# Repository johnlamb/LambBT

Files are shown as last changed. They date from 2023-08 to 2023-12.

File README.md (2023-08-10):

# LambBT
## Split wireless keyboard

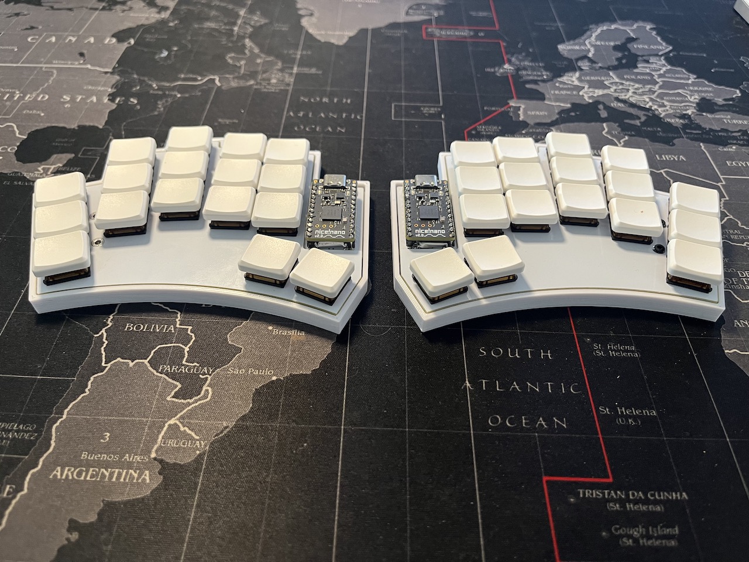
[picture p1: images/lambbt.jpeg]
LambBT


A small 34 key split wireless keyboard with Choc V1 switches heavily inspired by the Sweep family and Architeuthis Dux. The columns have the same splay as the AD and is great for starting to experiment with splays.

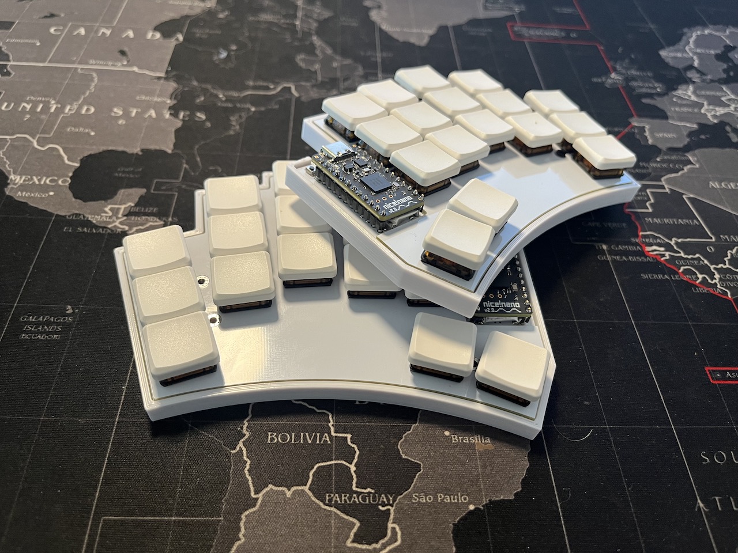
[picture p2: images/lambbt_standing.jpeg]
LambBT Side


The keyboard uses hotswap and a top plate together with a 3D printed case with M2 insets. 

Socketing the Nice!Nano v2 allows the battery to fit under the MCU. The MCU can face both up and down on either split. For a face up orientation, as in the pictures, solder the MCU bridges on the top. For a face down orientation, solder the MCU bridges on the bottom/back side.

I opted to skip an external battery JST connector and instead use two battery holes to solder the wires. Ensure right polarity, the positive end (usually red) goes in the left hole on the left split, and the right hole on the right split(towards the key switches) whereas the negative/ground (usually black) goes in the outer hole (right hole on the left split and left hole on the right split).

On/Off switch with a case cutout and a reset switch that wont be accidentally triggered.

## Design
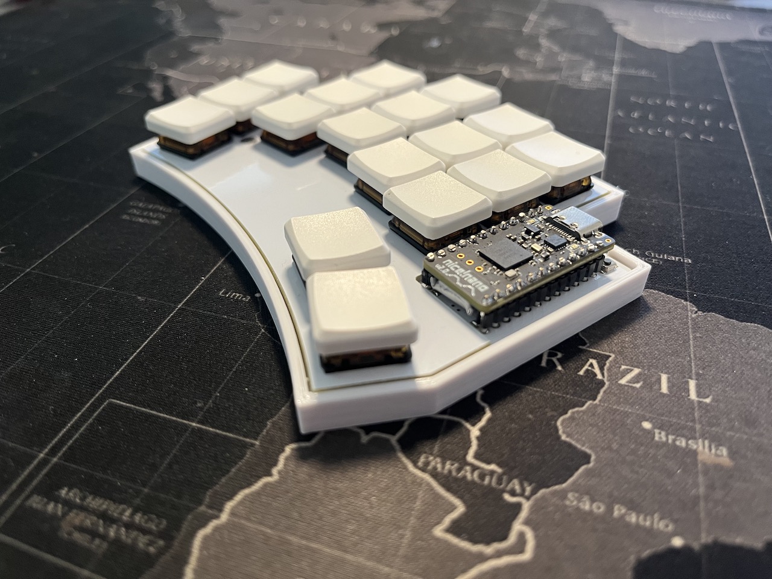
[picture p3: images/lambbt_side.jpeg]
LambBT Detail


Designed from the ground up using Ergogen and the routing in KiCad. Files for the pcb and case are in the [Ergogen](ergogen) folder together with ready made gerber files for both the pcb and plate.

Stl-files for the case are in the [output/case](ergogen/output/cases) folder.

## Build

To build for yourself, mae sure Ergogen CLI is installed. Then download/clone this repo, stand in the ergogen folder and issue the `ergogen .` command.

To also generate the case files, use the full:
`ergogen . && for i in output/cases/*.jscad; do npx @jscad/cli@1 "$i" -of stla ; done`

## Firmware
I use ZMK as firmware. You can find tested firmware and an initial keymap in the [lambbt_zmk repo](https://github.com/johnlamb/lambbt_zmk). Observer the standard keymap is Colemak-DH, if you want regular QWERTY, use the "default.keymap" file in the repo.

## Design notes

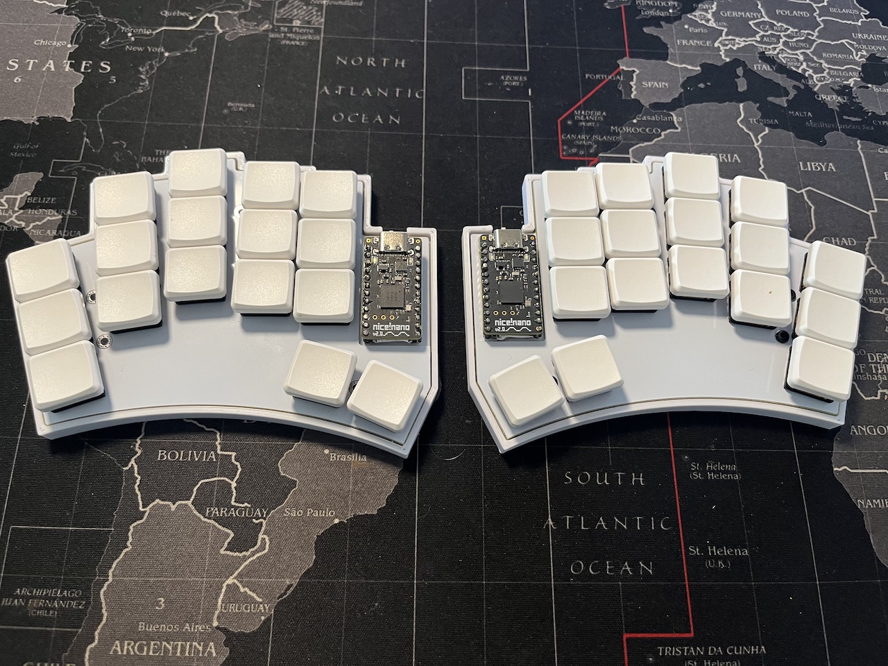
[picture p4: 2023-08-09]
images/lambbt2.jpeg

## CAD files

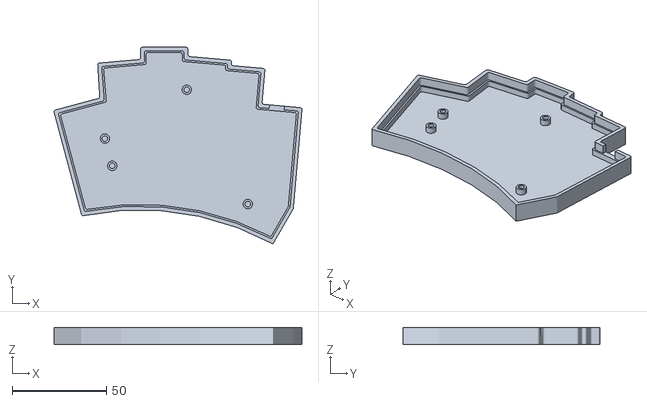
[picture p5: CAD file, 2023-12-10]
ergogen/output/cases/case_magnetic.stl
131.8 x 104.6 x 9.20

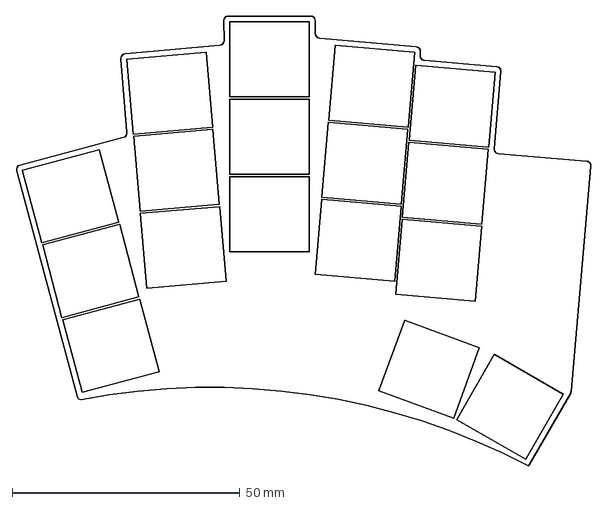
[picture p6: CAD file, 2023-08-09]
ergogen/output/outlines/combo.dxf
126.2 x 98.7 mm

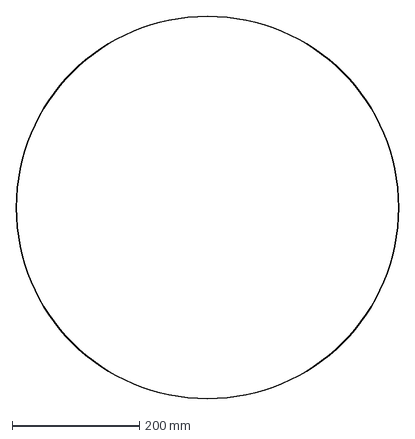
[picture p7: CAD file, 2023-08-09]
ergogen/output/outlines/cutout_circle_large.dxf
600.0 x 600.0 mm

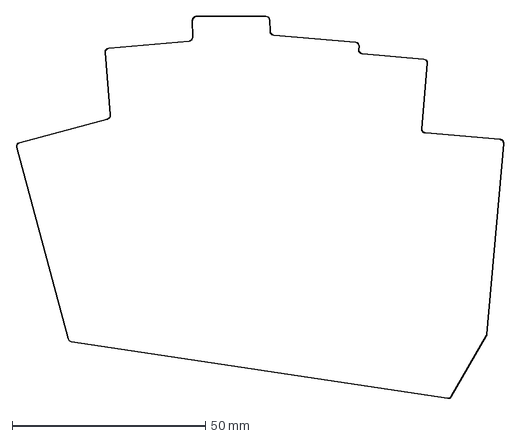
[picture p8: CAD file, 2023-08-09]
ergogen/output/outlines/board.dxf
126.2 x 99.0 mm

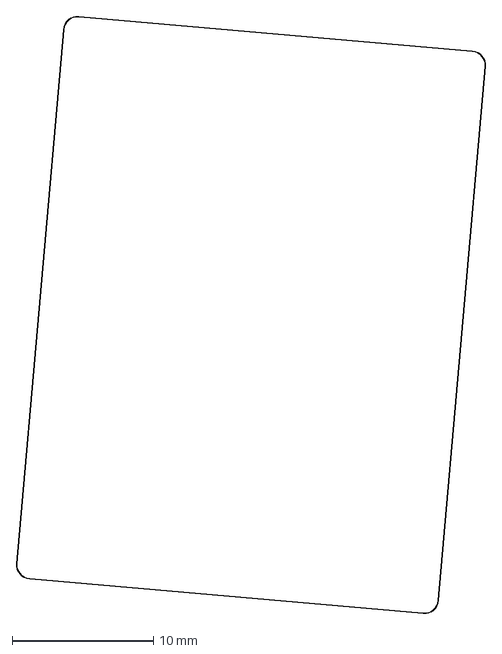
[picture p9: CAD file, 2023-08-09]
ergogen/output/outlines/mcucutout.dxf
33.3 x 42.4 mm

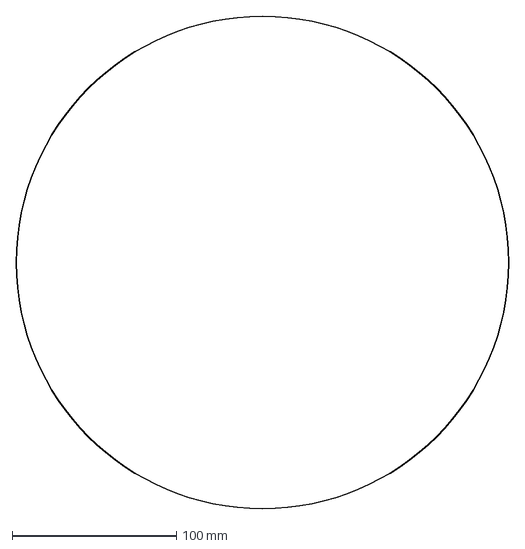
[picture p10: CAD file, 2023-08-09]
ergogen/output/outlines/cutout_circle_small.dxf
300.0 x 300.0 mm

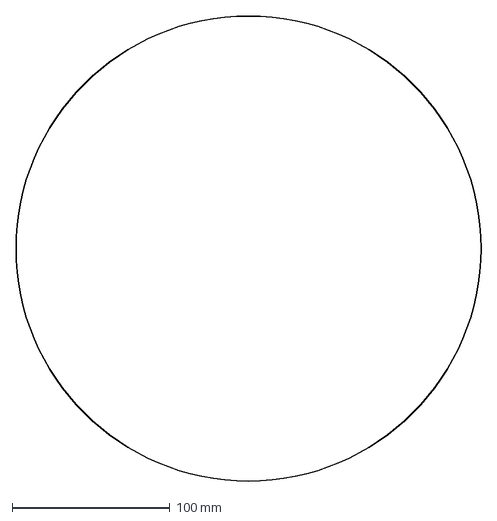
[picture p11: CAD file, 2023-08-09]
ergogen/output/outlines/cutout_circle_small_wall.dxf
295.0 x 295.0 mm

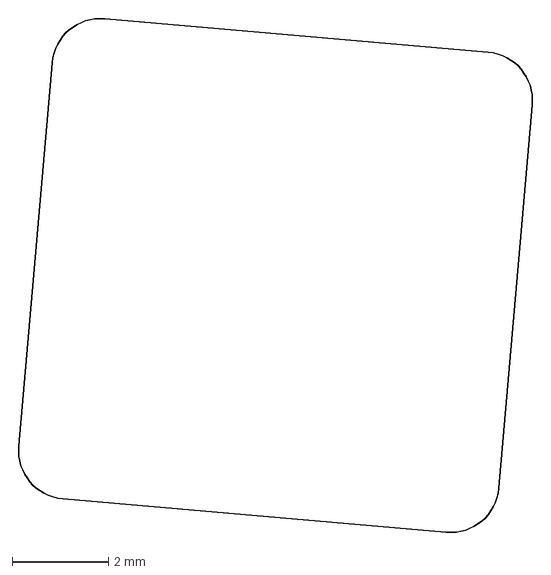
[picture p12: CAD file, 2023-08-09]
ergogen/output/outlines/usbcutout.dxf
10.8 x 10.8 mm

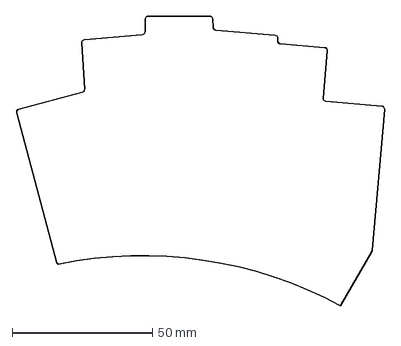
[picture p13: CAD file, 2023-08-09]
ergogen/output/outlines/xlplate.dxf
131.5 x 103.4 mm

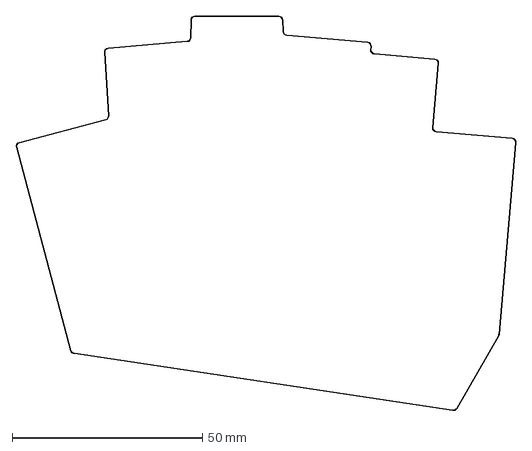
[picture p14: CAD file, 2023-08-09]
ergogen/output/outlines/xlboard.dxf
131.5 x 103.7 mm

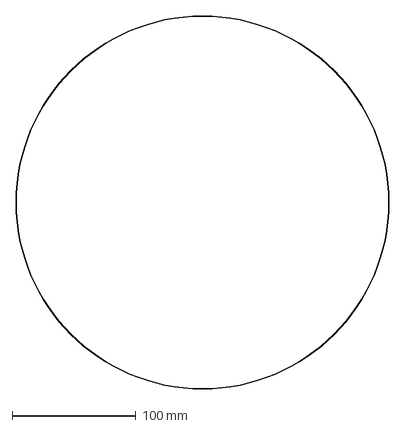
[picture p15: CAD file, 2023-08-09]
ergogen/output/outlines/cutout_circle_small_inner_inner_wall.dxf
300.8 x 300.8 mm

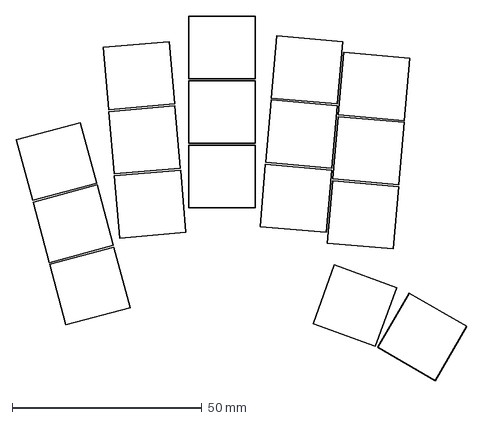
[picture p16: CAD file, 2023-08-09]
ergogen/output/outlines/keys.dxf
118.7 x 96.1 mm

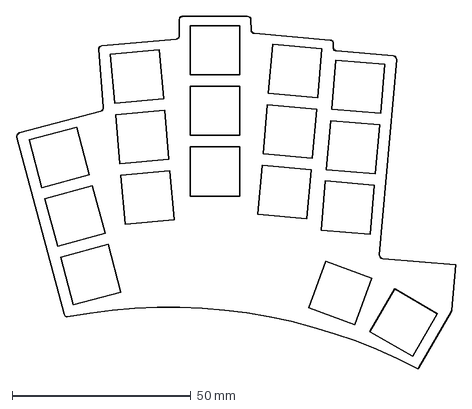
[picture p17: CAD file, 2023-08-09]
ergogen/output/outlines/plate.dxf
123.0 x 98.7 mm

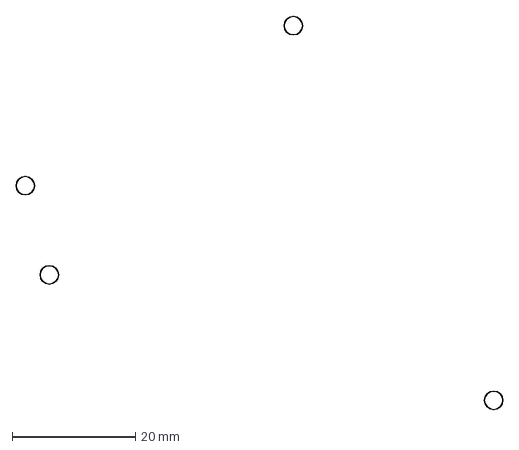
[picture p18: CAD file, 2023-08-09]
ergogen/output/outlines/mounting.dxf
79.0 x 63.8 mm

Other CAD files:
ergogen/output/outlines/cutout_circle_small_inner_wall.dxf
ergogen/output/outlines/standoff.dxf
ergogen/output/outlines/pcb.dxf
ergogen/output/outlines/switches.dxf

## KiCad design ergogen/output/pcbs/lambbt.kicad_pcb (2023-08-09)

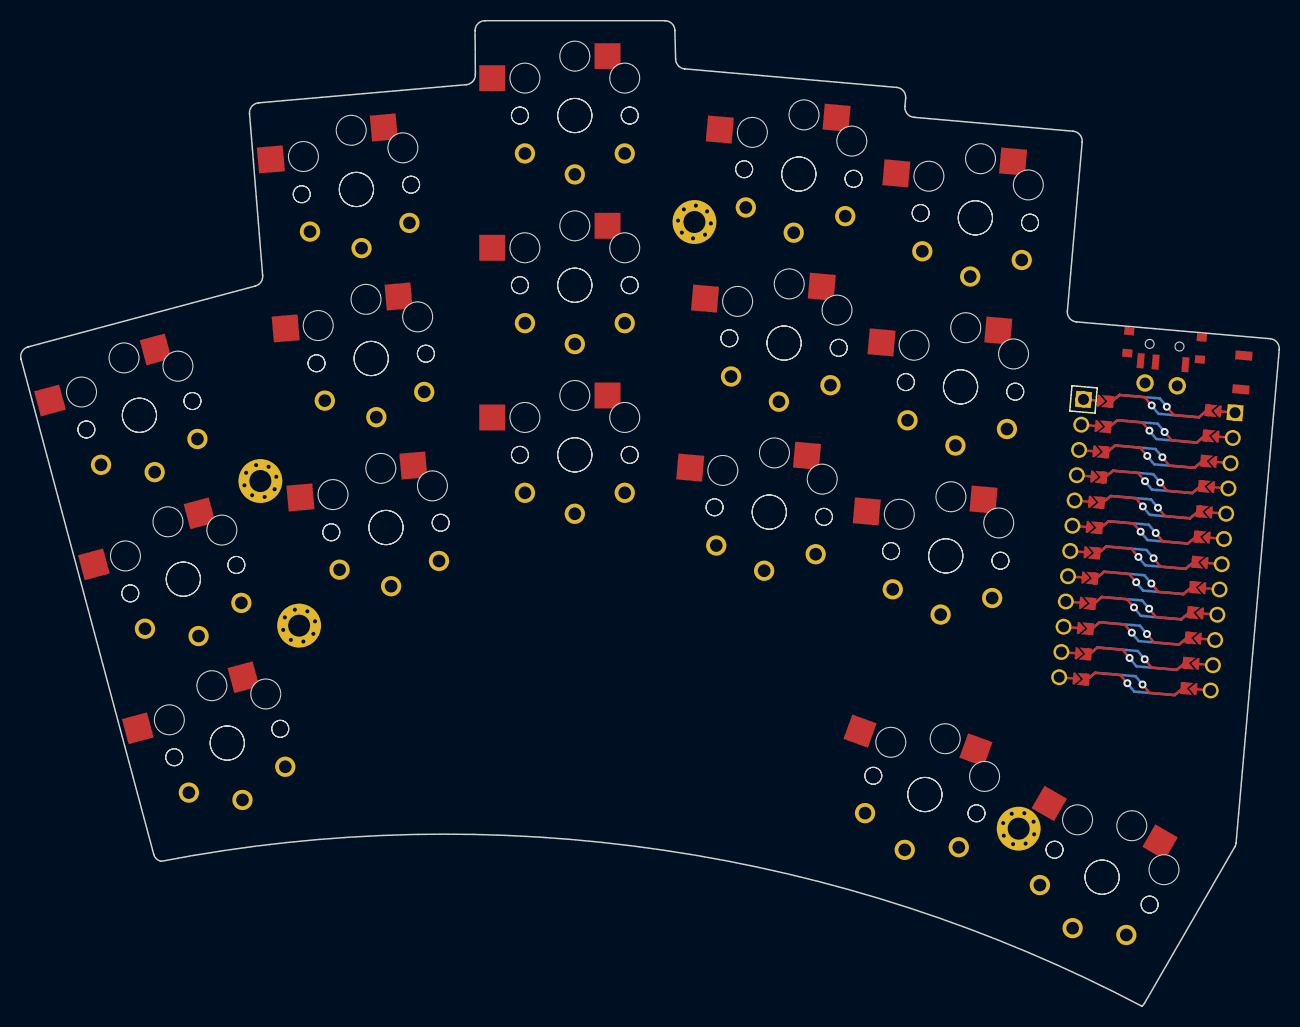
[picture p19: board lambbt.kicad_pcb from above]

Board: 2 copper layers, 126.1 x 98.7 mm, 39 parts (0 on the bottom side), 18 nets.

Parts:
MCU1: ProMicro
S1, S2, S3, S4, S5, S6, S7, S8, S9, S10, S11, S12, S13, S14, S15, S16, S17, S18, S19, S20, S21, S22, S23, S24, S25, S26, S27, S28, S29, S30, S31, S32, S33, S34: PG1350
_4, _5, _6, _7: MountingHole_2.2mm_M2_Pad_Via

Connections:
GND: MCU1.2, MCU1.21, MCU1.22, S1.2, S2.2, S3.2, S4.2, S5.2, S6.2, S7.2, S8.2, S9.2, S10.2, S11.2, S12.2, S13.2, S14.2, S15.2, S16.2, S17.2, S18.2, S19.2, S20.2, S21.2, S22.2, S23.2, S24.2, S25.2, S26.2, S27.2, S28.2, S29.2, S30.2, S31.2, S32.2, S33.2, S34.2
P0: MCU1.23, S14.1, S31.1
P1: MCU1.24, S15.1, S32.1
P2: MCU1.20, S13.1, S30.1
P3: MCU1.19, S12.1, S29.1
P4: MCU1.18, S11.1, S28.1
P5: MCU1.17, S10.1, S27.1
P6: MCU1.16, S9.1, S26.1
P7: MCU1.15, S8.1, S25.1
P8: MCU1.14, S7.1, S24.1
P9: MCU1.13, S6.1, S23.1
P10: MCU1.12, S5.1, S22.1
P14: MCU1.10, S3.1, S20.1
P15: MCU1.9, S2.1, S19.1
P16: MCU1.11, S4.1, S21.1
P18: MCU1.8, S1.1, S18.1
P19: MCU1.7, S16.1, S33.1
P20: MCU1.6, S17.1, S34.1

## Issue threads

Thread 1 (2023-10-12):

Complete list of hardware to build?

Mathrocker666, 2023-10-12:
Hey,

This keeb looks fantastic and I'd like to build one but I have a question: what exactly is needed to build it? M2 standoffs etc?

Thanks

johnlamb, 2023-10-13:
Thanks!
BOM:
2 pcbs, one for each side
2 MCUs, I am running Nice Nano v2
Legs and sockets for MCU socketing (https://docs.splitkb.com/hc/en-us/articles/360011263059-How-do-I-socket-a-microcontroller-)
2 batteries, I use 301230 3.7V 110mAh batteries that fits under the MCU when socketed.
34 hot swap sockets for Choc v1 switches
34 Choc v1 switches
34 choc v1 key caps
1 PCM12 surface mounted on/off switch
1 B3u1000 button for reset

Case:
3D print on left and one from the stl-files in the repo.
4 M2 threaded inserts
4 M2 screws, 4-5 mm long.

Closed 2023-10-13.

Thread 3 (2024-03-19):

Is top plate required to be used with the case?

ascodeasice, 2024-03-19:
Do I need the top plate to ensure the keyboard can fit in the case?

johnlamb, 2024-03-19:
No not needed, the pcb sits on a shelf on the bottom plate. Might even be easier to screw pcb to bottom plate without it. Purely aesthetic.

Closed 2024-03-19.

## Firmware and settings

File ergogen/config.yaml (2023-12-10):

units:
  kx: cx
  ky: cy

  pd: 2
  px: kx + pd
  py: ky + pd

  wpd: 2.5
  short_wpd: 0.5
  inner_wpd: -0.4

  # M2 screws
  screwsize: 1.5
  standoffsize: 2.5

  choc: 13.8

points:
  zones:
    matrix:
      # Fix placement on KiCAD sheet.
      anchor:
        shift: [150, -150]
      key:
        padding: 1ky
        spread: 1kx
      columns:
        pinky:
          key:
            splay: 15
          rows:
            bottom:
                column_net: P18
            home:
                column_net: P15
            top:
                column_net: P14
        ring:
          key:
            stagger: 17
            splay: -10
            origin: [0, -ky]
          rows:
            bottom:
                column_net: P16
            home:
                column_net: P10
            top:
                column_net: P9
        middle:
          key:
            stagger: 17/3
            splay: -5
            origin: [0, -ky]
          rows:
            bottom:
                column_net: P8
            home:
                column_net: P7
            top:
                column_net: P6
        index:
          key:
            stagger: -17/3
            splay: -5
            origin: [0, -ky]
          rows:
            bottom:
                column_net: P5
            home:
                column_net: P4
            top:
                column_net: P3
        inner:
          key:
            stagger: -17/6
          rows:
            bottom:
                column_net: P2
            home:
                column_net: P0
            top:
                column_net: P1
      rows:
        bottom:
        home:
        top:
    thumbs:
      key: 
        padding: 1ky
        spread: 1kx
      anchor:
        ref: matrix_inner_bottom
        shift: [0,-24]
      columns:
        inner:
          key:
            splay: -15
            column_net: P19
        outer:
          key:
            splay: -10
            origin: [-9, -9.5]
            column_net: P20
      rows:
        cluster:
outlines:
  keys:
    - what: rectangle
      where: true
      bound: false
      size: [kx-0.5, ky-0.5]
  switches:
    - what: rectangle
      where: true
      bound: false
      size: [choc, choc]
  cutout_circle_small:
    - what: circle
      radius: 150
      where:
        ref: matrix_middle_bottom
        shift: [-13,-188]
  cutout_circle_small_wall:
    - what: circle
      radius: 150-wpd
      where:
        ref: matrix_middle_bottom
        shift: [-13,-188]
  cutout_circle_small_inner_wall:
    - what: circle
      radius: 150-short_wpd
      where:
        ref: matrix_middle_bottom
        shift: [-13,-188]
  cutout_circle_small_inner_inner_wall:
    - what: circle
      radius: 150-inner_wpd
      where:
        ref: matrix_middle_bottom
        shift: [-13,-188]
  cutout_circle_large:
    - what: circle
      radius: 300
      where:
        ref: matrix_middle_bottom
        shift: [-38,-340]
  board:
    - what: polygon
      operation: stack
      points:
        - ref: matrix_pinky_top
          shift: [-0.5px, 0.5py]
        - ref: matrix_pinky_bottom
          shift: [-0.5px, -0.5py]
        - ref: thumbs_outer_cluster
          shift: [0.5px, -0.5py]
        - ref: thumbs_outer_cluster
          shift: [0.5px, 0.5py]

        -
          - ref: matrix_inner_top
            affect: r
          - shift: [0,2.675py]

        - ref: matrix_inner_top
          shift: [0.5px, -0.5py]
        - ref: matrix_inner_top
          shift: [0.5px, 0.5py]
        - ref: matrix_inner_top
          shift: [-0.5px+pd, 0.5py]

        - ref: matrix_index_top
          shift: [0.5px, 0.5py] 
        - ref: matrix_index_top
          shift: [-0.66px, 0.5py] 

        - ref: matrix_middle_top
          shift: [0.5px, 0.5py]
        - ref: matrix_middle_top
          shift: [-0.5px, 0.5py]

        - ref: matrix_ring_top
          shift: [0.64px, 0.5py]
        - ref: matrix_ring_top
          shift: [-0.5px, 0.5py]
        
        - ref: matrix_pinky_top
          shift: [0.77px, 0.5py]
      fillet: 1
  _case_board:
    - what: polygon
      operation: stack
      points:
        - ref: matrix_pinky_top
          shift: [-0.5px-short_wpd, 0.5py+short_wpd]
        - ref: matrix_pinky_bottom
          shift: [-0.5px-short_wpd, -0.5py-short_wpd]
        - ref: thumbs_outer_cluster
          shift: [0.5px+short_wpd, -0.5py-short_wpd]
        - ref: thumbs_outer_cluster
          shift: [0.5px+short_wpd, 0.5py+short_wpd]

        -
          - ref: matrix_inner_top
            affect: r
          - shift: [0,2.675py+short_wpd/2]

        - ref: matrix_inner_top
          shift: [0.5px+short_wpd, -0.5py+short_wpd]
        - ref: matrix_inner_top
          shift: [0.5px+short_wpd, 0.5py+short_wpd]
        - ref: matrix_inner_top
          shift: [-0.5px+pd+short_wpd, 0.5py+short_wpd]
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

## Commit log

2023-08-09 Case shelf
2023-08-10 Clearlify battery connections
2023-12-10 Updated case and added magnetic case
    [case_magnetic.stl]
